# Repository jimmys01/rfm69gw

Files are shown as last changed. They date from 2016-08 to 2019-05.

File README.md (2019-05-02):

# RFM69GW

This is a RFM69 gateway for an ESP8266-based custom board.

The project is currently in beta-stage with a working hardware prototype and full featured code. Both the code, libraries and eagle schematics and board layout are free and open source and can be found in this repository.

## Hardware

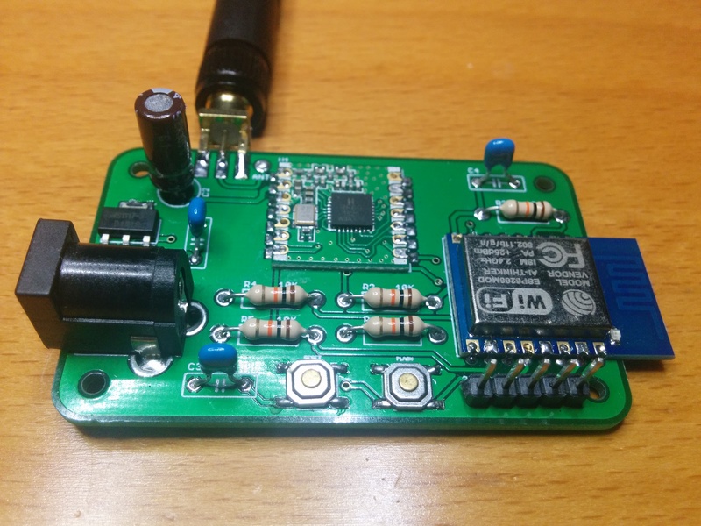
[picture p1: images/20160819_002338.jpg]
RFM69GW board - front view


The custom PCB has the minimum required components:

* ESP12 footprint
* RFM69CW module footprint
* Two push buttons to RESET and FLASH the board
* A 2.1 5mm jack for powering with AMS1117-3V3 to power the modules
* Filtering and push  up resistors and capacitors
* A 5 pin header to program it
* An edge footprint for an SMA or RP-SMA antenna

The ESP12 and RFM69CW modules are wired according to the following schema:

| ESP12  | NodeMCU | RFM69CW |
|---|---|---|
| GPIO5  | D1 | DIO0 |
| GPIO12 | D6 | MISO |
| GPIO13 | D7 | MOSI |
| GPIO14 | D5 | SCK |
| GPIO15 | D8 | NSS |
| GPIO16 | D0 | RST |

Note: there was an error in the ESP12 footprint for version 0.1 of the board: GPIO 4 and 5 were swapped. The schematic showed the IRQ pin to be GPIO4, but the GPIO5 pin was the pin in use.

You can also use your own hardware, SPI pins will probably be the same, only remember to change the pin numbers for SPI_CS and interruption in the RFM69Manager.h file.

```
#define SPI_CS              SS   // GPIO15 (D8)
#define IRQ_PIN             5    // GPIO5  (D1)
#define USE_RESET_PIN       true // Only if RFM's RESET pin connected.
#define RESET_PIN           16   // GPIO16 (D0)
```

## Firmware

* **WebServer for configuration** using the great [PureCSS framework][1]
* **Flashing firmware Over-The-Air** (OTA)
* Up to **3 configurable WIFI networks**
* **MQTT support**
* Arbitrary number of **mappings between nodes/keys and MQTT topics** (as long as there is free memory available)
* Optional default topic for non mapped nodes/keys.
* Configurable IP and Heartbeat topics
* Visual status of the received messages via the ESP12 LED

The project uses a series of state-of-the-art libraries:

* [RFM69_ATC][5] by Felix Rusu and Thomas Studwell with a small change (check patch above)
* [PubSubClient][3] by Nick O'Leary
* [ArduinoJson][4] by Benoit Blanchon
* [Embedis][7] by PatternAgents
* [PureCSS][1] by Yahoo
* And some of the libraries from the [Arduino core for ESP8266][10], by @igrr (Ivan Grokhotkov), @Links2004, @me-no-dev et a,.

## Flashing

The board has a header with 3V3, GND, RX and TX pins, and two buttons for RESET and FLASH. Connect the pins to your favorite FTDI-like programmer. Remember: **only 3V3 voltage** and connect RX to your FTDI TX pin and TX to your RX pin.

To enter flash mode you have to hold the FLASH button pressed while reseting the board with the RESET button.

The project is ready to be build using [PlatformIO][2].
Please refer to their web page for instructions on how to install the builder. Once installed:

```bash
> platformio run --target upload -e wire
> platformio run --target uploadfs -e wire
```

Once you have flashed it you can flash it again over-the-air using the ```ota``` environment:

```bash
> platformio run --target upload -e ota
> platformio run --target uploadfs -e ota
```

When using OTA environment it defaults to the IP address of the device in SoftAP mode. If you want to flash it when connected to your home network best way is to supply the IP of the device:

```bash
> platformio run --target upload -e ota --upload-port 192.168.1.151
> platformio run --target uploadfs -e ota  --upload-port 192.168.1.151
```

Library dependencies not included in the project are automatically managed via PlatformIO Library Manager.

## Usage

On normal boot (i.e. button not pressed) it will execute the firmware. It configures the radio, the SPIFFS memory access, the WIFI, the WebServer and MQTT connection.

Obviously the default values for WIFI network and MQTT will probably not match your requirements. The device will start in Soft AP creating a WIFI SSID named "RFM69_GATEWAY". Connect with phone, PC, laptop, whatever to that network, password is "fibonacci". Once connected browse to 192.168.4.1 and you will be presented a configuration page where you will be able to define up to 3 possible WIFI networks and the MQTT configuration parameters, and topic mappings.

It will then try to connect to the configured WIFI networks one after the other. If none of the 3 attempts succeed it will default to SoftAP mode again. Once connected it will try to connect the MQTT server.

You can configure several aspects, most importantly:

* up to 3 **wifi SSID and password**
* **MQTT server, port** and optionally **user and password**
* **MQTT topics for IP and heartbeat messages**
* **nodeID**, **key** and **topic** to map a given key from a given nodeID to a certain MQTT topic
* a **defaultTopic**, if defined, will be used as a default topic for any combination of nodeID+key not mapped. You can use {nodeid} and {key} as placeholders that will be replaced in execution time.

Messages from the nodes (probably Monteinos) do have to stick to one of these formats:

```
<key>:<value>
<key>:<value>:<packetID>
```

The first one being the default for Rusu's MotionNotes, for instance. "BAT:3812" could be a valid payload to notify battery status. The ```send``` method of the RFM69Manager library included will take care of the formatting. It will also add a correlative packetID that will be used in the gateway to detect duplicates or missing packages.

The RFM69Manager library inherits from RFM69_ATC, so it supports [Automatic Transmission Control][8] that improves battery life by reducing radio power dynamically.

The device will publish its IP to the given topic upon reboot and will send a heartbeat message every 60 seconds.

## Troubleshooting

After flashing the firmware via serial do a hard reset of the device (unplug & plug). There is an issue with the ESP.reset() method that may stuck the device after an OTA update. Check [https://github.com/esp8266/Arduino/issues/1017][3] for more info.

[1]: http://purecss.io/
[2]: http://www.platformio.org
[3]: https://github.com/knolleary/pubsubclient
[4]: https://github.com/bblanchon/ArduinoJson
[5]: https://github.com/LowPowerLab/RFM69
[6]: https://github.com/LowPowerLab/SPIFlash
[7]: https://github.com/thingSoC/embedis
[8]: https://lowpowerlab.com/blog/2015/11/11/rfm69_atc-automatic-transmission-control/
[9]: https://github.com/xoseperez/SPIFlash
[10]: https://github.com/esp8266/Arduino

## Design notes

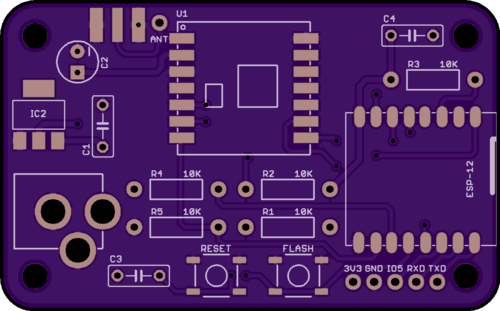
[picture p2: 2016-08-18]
schema/rfm69gw-0.3.20160731-top.png

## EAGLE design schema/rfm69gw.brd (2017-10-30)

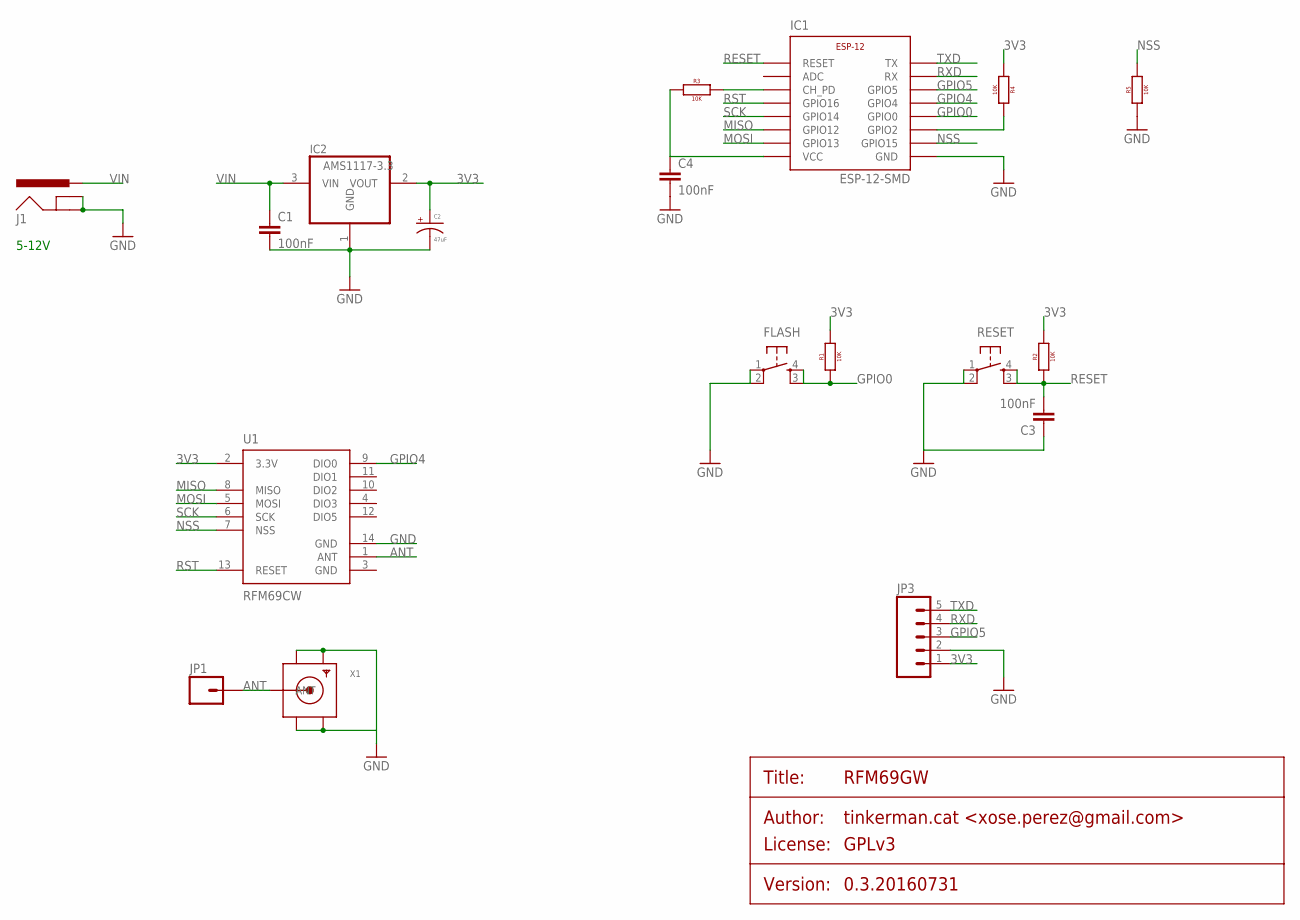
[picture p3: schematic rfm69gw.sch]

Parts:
C1, C3, C4: 100nF; C050-025X075
C2: 47uF; CPOL-RADIAL-10UF-25V
FLASH: TACTILE_BUTTON_SMD; TACTILE-BUTTON-SMD
IC1: ESP-12-SMD
IC2: AMS1117-3.3; SOT223
J1: POWER_JACKPTH; POWER_JACK_PTH
JP1: M01SMDNS; 1X01NS
JP3: M05PTH; 1X05
R1, R2, R3, R4, R5: 10K; AXIAL-0.4
RESET: TACTILE_BUTTON_SMD; TACTILE-BUTTON-SMD
U1: RFM69CW; RFM69CW-XXXS2
X1: SMACONNECTOR_EDGE; SMA_EDGELAUNCH

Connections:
3V3: C2.1 (+), C4.1, IC1.VCC, IC2.2 (VOUT), JP3.1, R1.P$2 (2), R2.P$2 (2), R3.P$1 (1), R4.P$1 (1), U1.2 (3.3V)
ANT: JP1.1, U1.1 (ANT), X1.P (ANT)
GND: C1.2, C2.2 (-), C3.1, C4.2, FLASH.1 (SWA1), FLASH.2 (SWB1), IC1.GND, IC2.1 (GND), J1.GND, J1.GNDBREAK, JP3.2, R5.P$1 (1), RESET.1 (SWA1), RESET.2 (SWB1), U1.3 (GND), U1.14 (GND), X1.GND@1 (GND4), X1.GND@2 (GND3), X1.GND@3 (GND2), X1.GND@4 (GND1)
GPIO0: FLASH.3 (SWB2), FLASH.4 (SWA2), IC1.GPIO0, R1.P$1 (1)
GPIO4: IC1.GPIO4, U1.9 (DIO0)
GPIO5: IC1.GPIO5, JP3.3
MISO: IC1.GPIO12, U1.8 (MISO)
MOSI: IC1.GPIO13, U1.5 (MOSI)
unnamed: IC1.CH_PD, R3.P$2 (2)
unnamed: IC1.GPIO2, R4.P$2 (2)
NSS: IC1.GPIO15, R5.P$2 (2), U1.7 (NSS)
RESET: C3.2, IC1.RESET, R2.P$1 (1), RESET.3 (SWB2), RESET.4 (SWA2)
RST: IC1.GPIO16, U1.13 (RESET)
RXD: IC1.RX, JP3.4
SCK: IC1.GPIO14, U1.6 (SCK)
TXD: IC1.TX, JP3.5
VIN: C1.1, IC2.3 (VIN), J1.PWR

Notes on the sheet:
5-12V

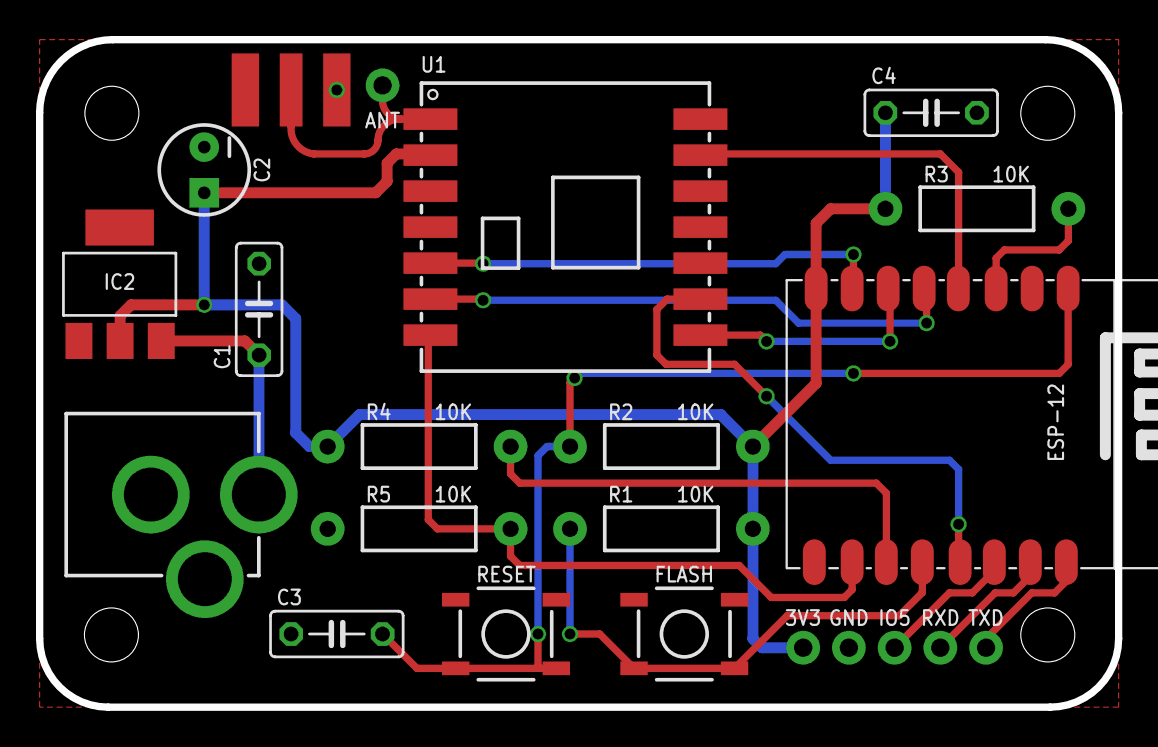
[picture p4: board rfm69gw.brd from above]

Board: 2 copper layers, 59.9 x 37.1 mm, 18 parts (0 on the bottom side), 17 nets.

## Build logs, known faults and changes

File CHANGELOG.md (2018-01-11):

# RFM69GW change log

The format is based on [Keep a Changelog](http://keepachangelog.com/)
and this project adheres to [Semantic Versioning](http://semver.org/).

## [1.0.1] 2018-01-11
### Changed
- Updated JustWifi library to 1.1.6
- Heartbeat every 60 seconds
- Show friendly uptime in Web UI

## [1.0.0] 2017-10-31
### Changed
- Migrating code base from ESPurna project
- Changes in the web UI
- WS and MQTT fixes and addons

## [0.9.4] 2017-02-14
### Changed
- Issue #3. Using forken Time.h library to prevent build error on Windows hosts

## [0.9.3] 2017-02-06
### Added
- EEPROM management commands from terminal interface

### Changed
- Defer reconnection when issued from web interface to allow the response to get out
- Improved MQTT and NTP connections
- Multiple small changes from ESPurna firmware

## [0.9.1] 2017-01-22
### Added
- Added messages tab in web interface with sorting and filtering

### Fixed
- Issue #2. Set max packet length in RFMManager::send to RF69_MAX_DATA_LEN
- Issue #2. Allow user to define packet separator, defaults to :
- Allow multi-packet websocket frames

## [0.9.0] 2016-12-01
### Added
- Added unique admin password (OTA, WIFI and WEB interface)
- Using ESPAsyncWebServer and AsyncMqttClient
- Added reset command to console

### Changed
- Updated gulp builder script
- Moved git submodule references to PlatformIO dependencies
- Overriden RFM69::select() method with custom DIV_CLOCK
- Replaced AJAX requests completely by WebSockets

## [0.3.1] 2016-11-17
- Imported changes from ESPurna project

## [0.3.1] 2016-10-03
- Initial working version

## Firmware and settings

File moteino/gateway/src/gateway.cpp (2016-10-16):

/*

ESP69GW

ESP8266 to RFM69 Gateway
Monteino gateway sample code
Based on sample code by Felix Rusu - http://LowPowerLab.com/contact

Copyright (C) 2016 by Xose Pérez <xose dot perez at gmail dot com>

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
*/

#include <RFM69Manager.h>
#include <SPI.h>
#include <SPIFlash.h>
//#include <WirelessHEX69.h>

// -----------------------------------------------------------------------------
// Configuration
// -----------------------------------------------------------------------------

#define NODEID              2
#define GATEWAYID           2
#define PROMISCUOUS         1
#define NETWORKID           164
#define FREQUENCY           RF69_868MHZ
#define ENCRYPTKEY          "fibonacci0123456"
#define IS_RFM69HW          0

#define SERIAL_BAUD         115200

#ifdef MOTEINO
    #define LED_PIN         9       // Moteinos have LEDs on D9
    #define FLASH_SS        8       // and FLASH SS on D8
    #define FLASH_ID        0xEF30  // EF30 for 4mbit  Windbond chip (W25X40CL)
    #define USE_FLASH       1
#endif

#ifdef JEELINK
    #define LED_PIN         9       // Jeenodes have LEDs on D9
    #define FLASH_SS        8       // and FLASH SS on D8
    #define FLASH_ID        0x2020  // 2020 for ??
    #define USE_FLASH       0
#endif

// -----------------------------------------------------------------------------
// Globals
// -----------------------------------------------------------------------------

#if USE_FLASH
    SPIFlash flash(FLASH_SS, FLASH_ID);
#endif
RFM69Manager radio;

// -----------------------------------------------------------------------------
// Utils
// -----------------------------------------------------------------------------

void blink(byte times, byte mseconds) {
    pinMode(LED_PIN, OUTPUT);
    for (byte i=0; i<times; i++) {
        digitalWrite(LED_PIN, LOW);
        delay(mseconds);
        digitalWrite(LED_PIN, HIGH);
        delay(mseconds);
    }
}

// -----------------------------------------------------------------------------
// Flash
// -----------------------------------------------------------------------------

#if USE_FLASH

void flashSetup() {

    if (flash.initialize()) {
        Serial.print("SPI Flash Init OK. Unique MAC = [");
        flash.readUniqueId();
        for (byte i=0;i<8;i++) {
            Serial.print(flash.UNIQUEID[i], HEX);
            if (i!=8) Serial.print(':');
        }
        Serial.println(']');
        blink(1, 50);

    } else {
        Serial.println("SPI Flash MEM not found (is chip soldered?)...");
        Serial.println(flash.readDeviceId());
        blink(5, 50);
    }

}

#endif

// -----------------------------------------------------------------------------
// RFM69
// -----------------------------------------------------------------------------

void radioMessage(packet_t * data) {

    blink(5, 1);

    Serial.print("[MESSAGE] messageID:");
    Serial.print(data->messageID);
    Serial.print(" senderID:");
    Serial.print(data->senderID);
    Serial.print(" targetID:");
    Serial.print(data->targetID);
    Serial.print(" packetID:");
    Serial.print(data->packetID);
    Serial.print(" name:");
    Serial.print(data->name);
    Serial.print(" value:");
    Serial.print(data->value);
    Serial.print(" rssi:");
    Serial.print(data->rssi);
    Serial.println();

}

void radioSetup() {
    delay(10);
    if (!radio.initialize(FREQUENCY, NODEID, NETWORKID, ENCRYPTKEY)) {
        Serial.println("[RADIO] Error initializing radio");
        while (true);
    }
    radio.promiscuous(PROMISCUOUS);
    radio.onMessage(radioMessage);
}

void radioLoop() {
    radio.loop();
}

// -----------------------------------------------------------------------------
// Common methods
// -----------------------------------------------------------------------------

void setup() {
    Serial.begin(SERIAL_BAUD);
    Serial.println();
    Serial.println();
    #if USE_FLASH
        flashSetup();
    #endif
    radioSetup();
    Serial.println();
    Serial.println();
}

void loop() {
    radioLoop();
    delay(1);
}

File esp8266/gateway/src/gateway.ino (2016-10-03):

/*

ESP69GW
MAIN MODULE

ESP8266 to RFM69 Gateway
Gateway code with suport for ESP8266-based boards

Copyright (C) 2016 by Xose Pérez <xose dot perez at gmail dot com>

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
*/

#include "version.h"
#include "defaults.h"
#include <WebSockets.h>
#include "RFM69Manager.h"

String getSetting(const String& key, String defaultValue = "");

struct _node_t {
  unsigned long count = 0;
  unsigned long missing = 0;
  unsigned long duplicates = 0;
  unsigned char lastPacketID = 0;
};

_node_t nodeInfo[255];

// -----------------------------------------------------------------------------
// Common methods
// -----------------------------------------------------------------------------

void processMessage(packet_t * data) {

    blink(3);

    #if DEBUG
        Serial.print("[MESSAGE]");
        Serial.print(" messageID:");
        Serial.print(data->messageID);
        Serial.print(" senderID:");
        Serial.print(data->senderID);
        Serial.print(" targetID:");
        Serial.print(data->targetID);
        Serial.print(" packetID:");
        Serial.print(data->packetID);
        Serial.print(" name:");
        Serial.print(data->name);
        Serial.print(" value:");
        Serial.print(data->value);
        Serial.print(" rssi:");
        Serial.print(data->rssi);
    #endif

    // Detect duplicates and missing packets
    // packetID==0 means device is not sending packetID info
    if (data->packetID > 0) {

        unsigned char gap = data->packetID - nodeInfo[data->senderID].lastPacketID;

        if (gap == 0) {
            #if DEBUG
                Serial.print(" DUPLICATED");
            #endif
            nodeInfo[data->senderID].duplicates = nodeInfo[data->senderID].duplicates + 1;
            return;
        }

        if ((gap > 1) && (data->packetID > 1)) {
            #if DEBUG
                Serial.print(" MISSING PACKETS!!");
            #endif
            nodeInfo[data->senderID].missing = nodeInfo[data->senderID].missing + gap - 1;
        }

    }

    nodeInfo[data->senderID].lastPacketID = data->packetID;
    nodeInfo[data->senderID].count = nodeInfo[data->senderID].count + 1;

    #if DEBUG
        Serial.println();
    #endif

    // Send info to websocket clients
    char buffer[60];
    sprintf_P(
        buffer,
        PSTR("{'senderID': %u, 'targetID': %u, 'packetID': %u, 'name': '%s', 'value': '%s', 'rssi': %d, 'duplicates': %d, 'missing': %d}"),
        data->senderID, data->targetID, data->packetID, data->name, data->value, data->rssi,
        nodeInfo[data->senderID].duplicates , nodeInfo[data->senderID].missing);
    webSocketSend(buffer);

    // Try to find a matching mapping
    bool found = false;
    unsigned int count = getSetting("mappingCount", "0").toInt();
    for (unsigned int i=0; i<count; i++) {
        if ((getSetting("nodeid" + String(i)) == String(data->senderID)) &&
            (getSetting("key" + String(i)) == data->name)) {
            mqttSend((char *) getSetting("topic" + String(i)).c_str(), (char *) String(data->value).c_str());
            found = true;
            break;
        }
    }

    if (!found) {
        String topic = getSetting("defaultTopic");
        if (topic.length() > 0) {
            topic.replace("{nodeid}", String(data->senderID));
            topic.replace("{key}", String(data->name));
            mqttSend((char *) topic.c_str(), (char *) String(data->value).c_str());
        }
    }

}

void blink(unsigned int time) {
    digitalWrite(LED_PIN, HIGH);
    delay(time);
    digitalWrite(LED_PIN, LOW);
}

// -----------------------------------------------------------------------------
// Hardware
// -----------------------------------------------------------------------------

void hardwareSetup() {
    Serial.begin(SERIAL_BAUD);
    Serial.println();
    Serial.println();
    pinMode(LED_PIN, OUTPUT);
}

void hardwareLoop() {


    // Heartbeat
    static unsigned long last_heartbeat = 0;

    if (mqttConnected()) {
        if ((millis() - last_heartbeat > HEARTBEAT_INTERVAL) || (last_heartbeat == 0)) {
            last_heartbeat = millis();
            mqttSend((char *) getSetting("hbTopic", HEARTBEAT_TOPIC).c_str(), (char *) "1");
            #if DEBUG
                Serial.print(F("[BEAT] Free heap: "));
                Serial.println(ESP.getFreeHeap());
            #endif
        }
    }

}

// -----------------------------------------------------------------------------
// Bootstrap methods
// -----------------------------------------------------------------------------

void setup() {
    hardwareSetup();
    settingsSetup();
    otaSetup();
    wifiSetup();
    mqttSetup();
    radioSetup();
    webServerSetup();
    webSocketSetup();
}

void loop() {
    hardwareLoop();
    settingsLoop();
    otaLoop();
    wifiLoop();
    mqttLoop();
    radioLoop();
    webServerLoop();
    webSocketLoop();
}

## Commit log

2016-08-18 Board images
    [rfm69gw.brd, rfm69gw.sch]
2016-08-19 Small fixes, linked modified SPIFlash library as submodule
    [gateway.ino]
2016-08-19 Fix some wrong comment sin README file
    [gateway.ino]
2016-10-03 Schema updated
    [rfm69gw.brd, rfm69gw.sch]
2016-12-04 Added reverse filtering and clear filters button
2017-01-02 Allow multi-packet websocket frames
2017-10-30 Small changes in the gateway layout
    [rfm69gw.brd]
2017-10-31 Fixing WS and MQTT for messages
    [general.h, main.ino, rfm69.ino]
2019-04-16 Pin ArduinoJson library to 5.6
    The API changed in 6+ and the project doesn't even
    compile with those current versions, so instead pin
    to the last the previous major version line.
2019-04-27 Update README for current code (and document NodeMCU)
    I worked through getting the project up and running on own hardware and
    came across a couple of discrepancies between the current codebase and
    the documentation:
    - Pin GPIO4 was listed to connect to RFM69 pin DIO0 (like the bug in the
    schematic), but the code defines pin GPIO5.
    - Lists a required patch to RFM69.cpp to change the SPI clock divider,
    but RFM69Manager.cpp does this already.
    - Lists a `#define` for `IRQ_NUM`, but this appears to be disregarded
    calculated automatically from the `IRQ_PIN` constant.
    - Flashing instructions pass the environment argument to the platformio
    command with the suffix `-debug`, but this results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
    [general.h]
2019-04-27 Implement RFH69 hardware reset at boot.
    The ESP module's GPIO16 and the RFM module's RST pin are already
    connected in the schematic and PCB design. However this connection
    wasn't documented in the README, and doesn't appear to be used in the
    software that I can tell.
    In my personal testing (with a NodeMCU) I was originall unable to get
    the radio to receive data. In my debugging I noticed another similar
    project *did* appear to work on the same physical breadboard test setup,
    which made me assume the difference was in software. The immediate and
    obvious difference was that the other project performed a hardware reset
    of the radio module before use. I added such a reset (following the
    datashe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
    [general.h, rfm69.ino]

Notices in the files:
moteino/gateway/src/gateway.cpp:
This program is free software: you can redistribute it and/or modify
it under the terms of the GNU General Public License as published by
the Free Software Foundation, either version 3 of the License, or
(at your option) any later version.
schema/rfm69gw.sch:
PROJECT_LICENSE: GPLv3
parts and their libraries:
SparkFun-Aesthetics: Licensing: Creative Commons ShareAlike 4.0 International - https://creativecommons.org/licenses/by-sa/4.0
